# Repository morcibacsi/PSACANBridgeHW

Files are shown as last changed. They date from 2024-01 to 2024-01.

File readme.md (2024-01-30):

# PSA CAN protocol bridge (hardware)

### What is it ?
This is the hardware needed for my [PSA CAN protocol bridge][psacanbridge] software.

### v1.4

It was designed using KiCad 7.0.6 as a standalone board with an ESP32-C3 SuperMini soldered in place. It uses the MCP2515 to connect to the CAN bus of the car and the internal CAN peripheral of the ESP32 for connecting to the retrofitted peripherals. The CAN transceiver used on this board is the TJA1050 (the schematics contains a TJA1042 but they are interchangeable).

### Schema

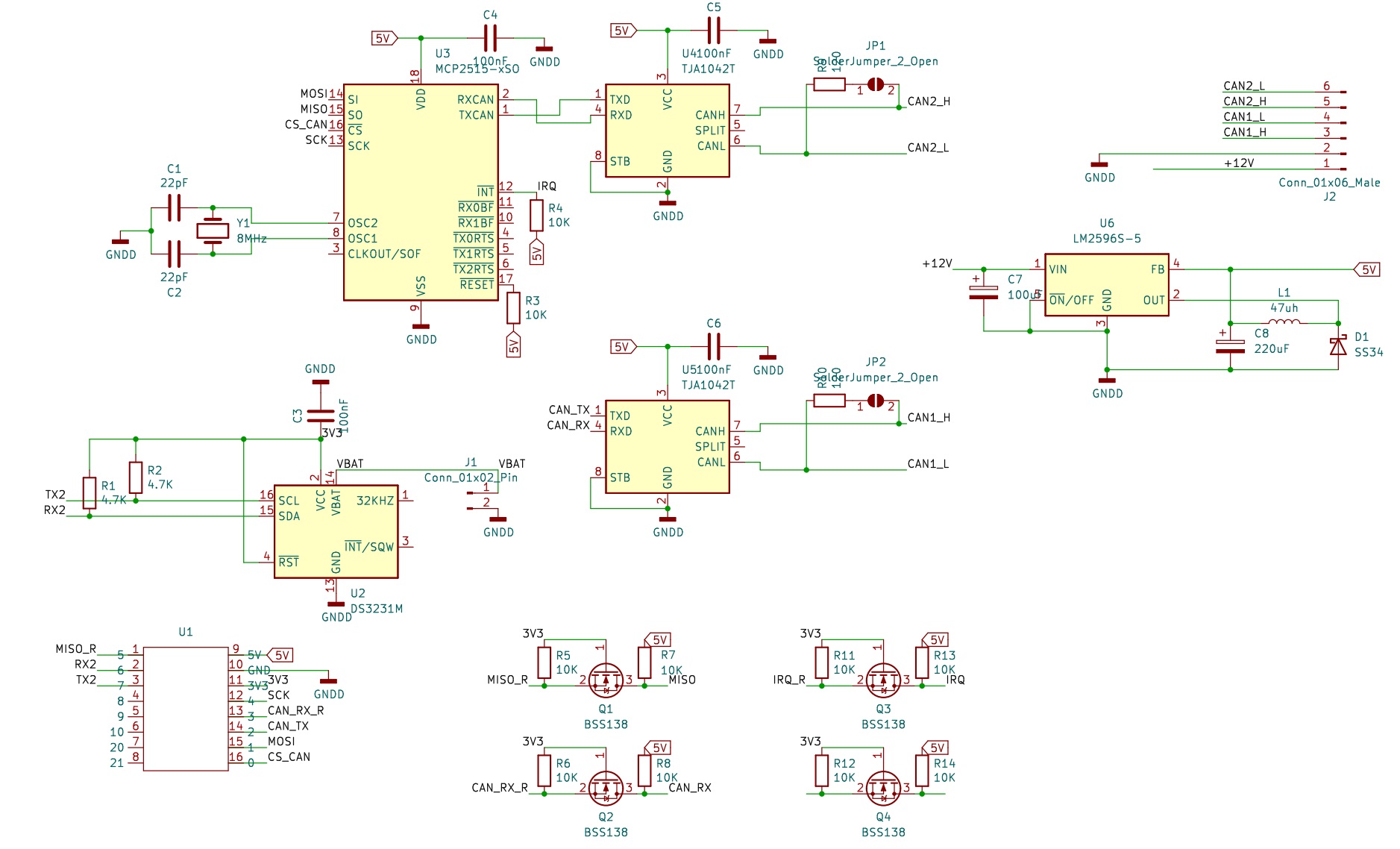
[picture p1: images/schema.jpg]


### PCB

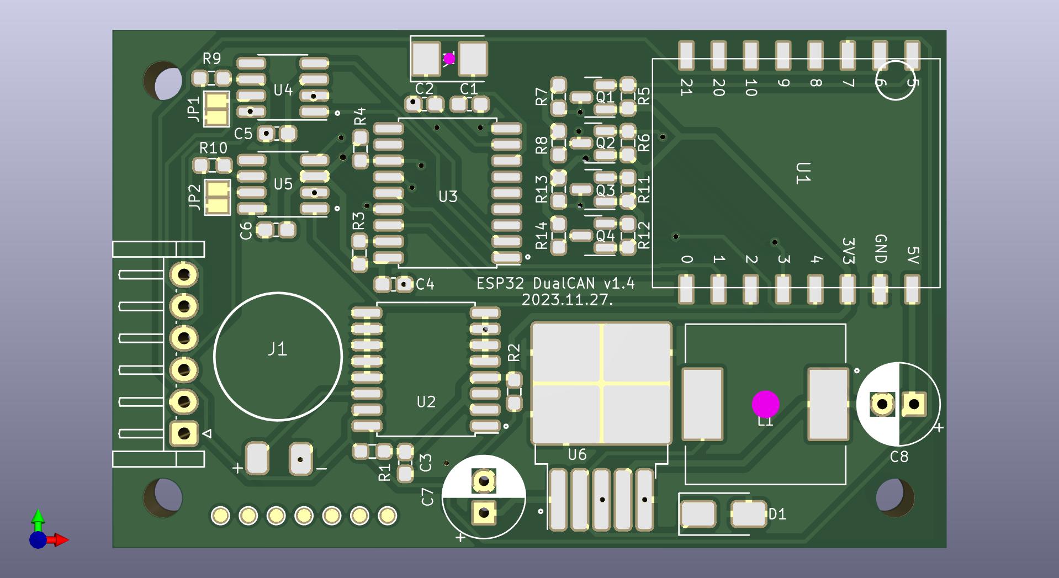
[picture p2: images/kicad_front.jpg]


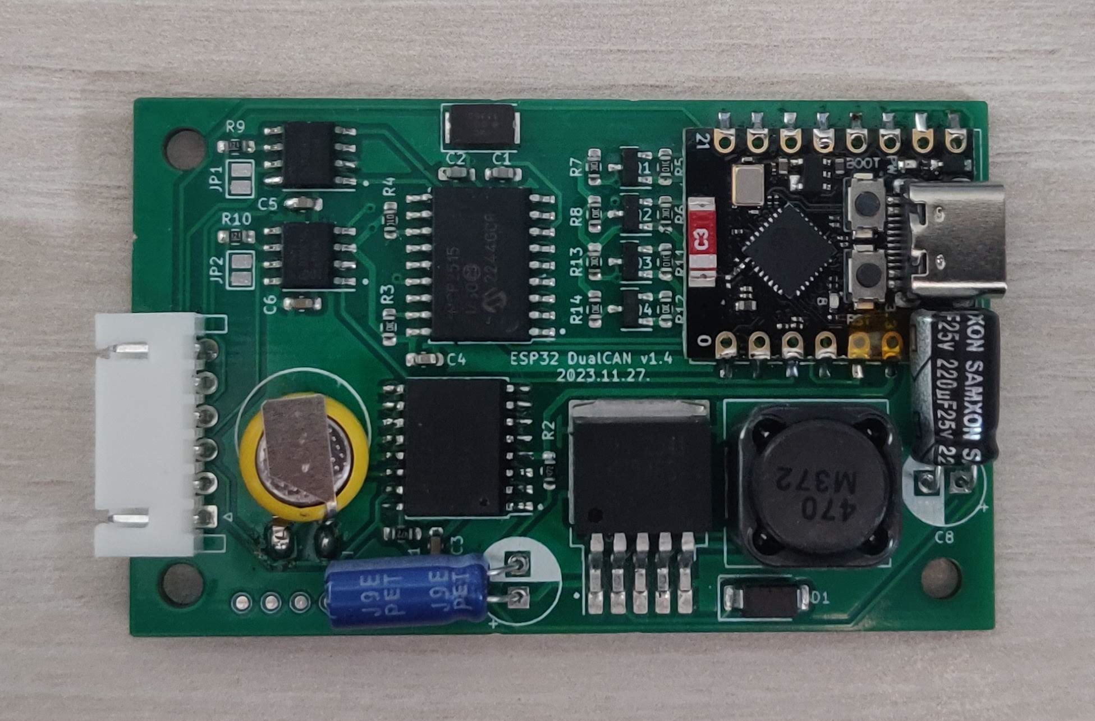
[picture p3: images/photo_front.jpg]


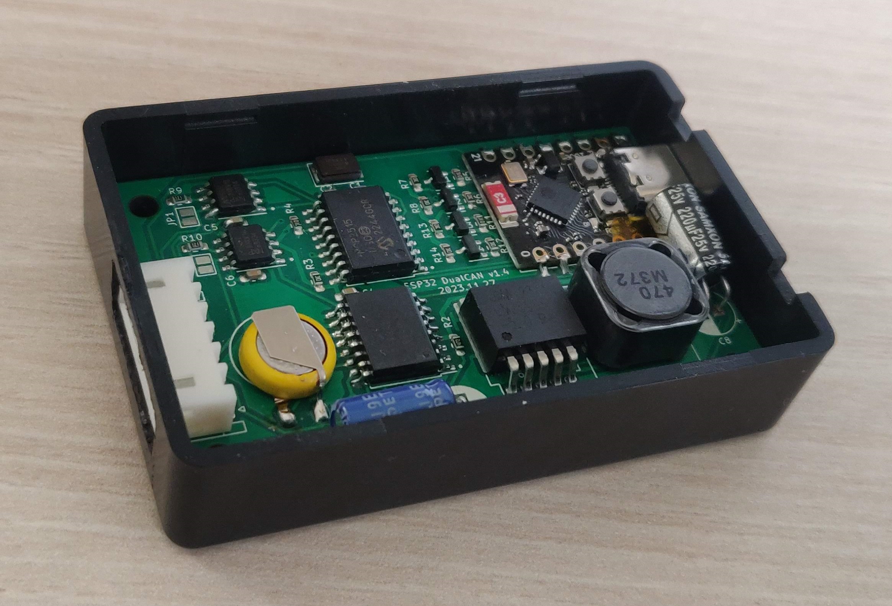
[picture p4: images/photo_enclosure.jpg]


### Assembly

The board was designed to be as compact as possible, so I suggest to send the manufacturing files to JLCPCB and order with assembly service. But in order to have a working board some soldering is also needed. You can find the necessary components in the next section.

💡 **By soldering JP1 and JP2 solder jumpers you can enable the CAN termination resistors (not needed in PSA cars)**

ESP32-C3 SuperMini

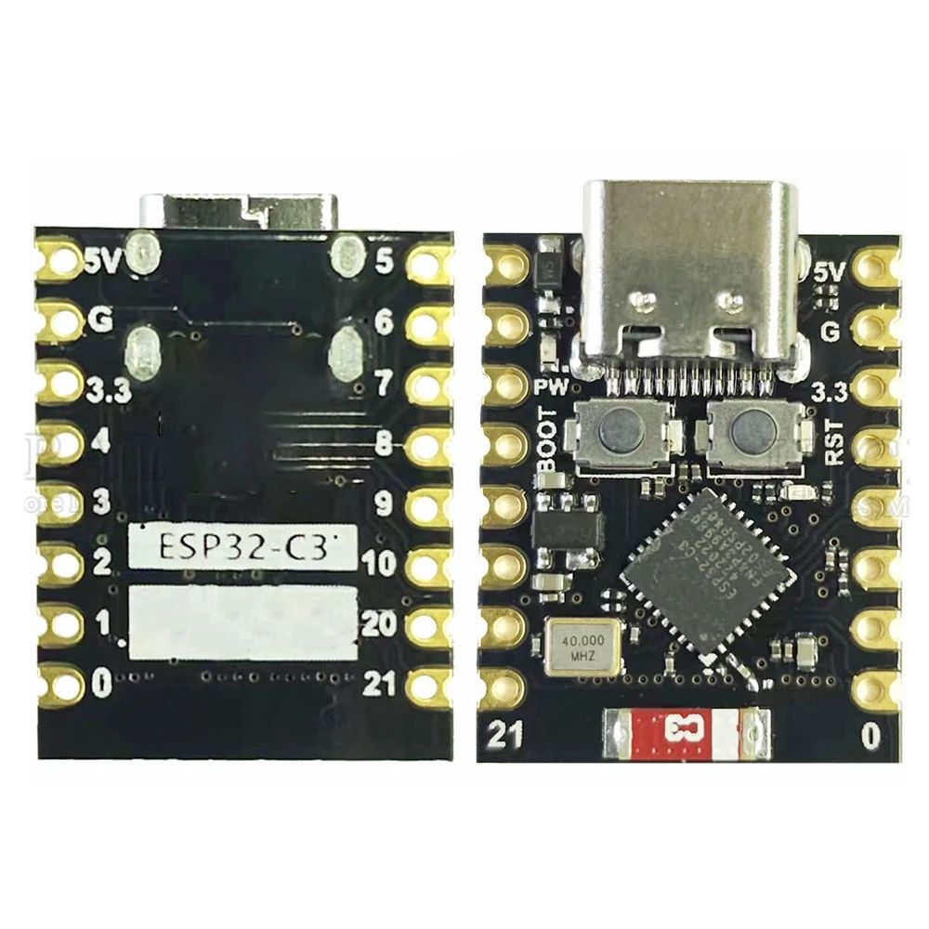
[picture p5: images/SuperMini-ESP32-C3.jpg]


I bought a [DS3231 real time clock module for Raspberry Pi][DS3231] and disassembled that and placed its parts to J1 and U2.

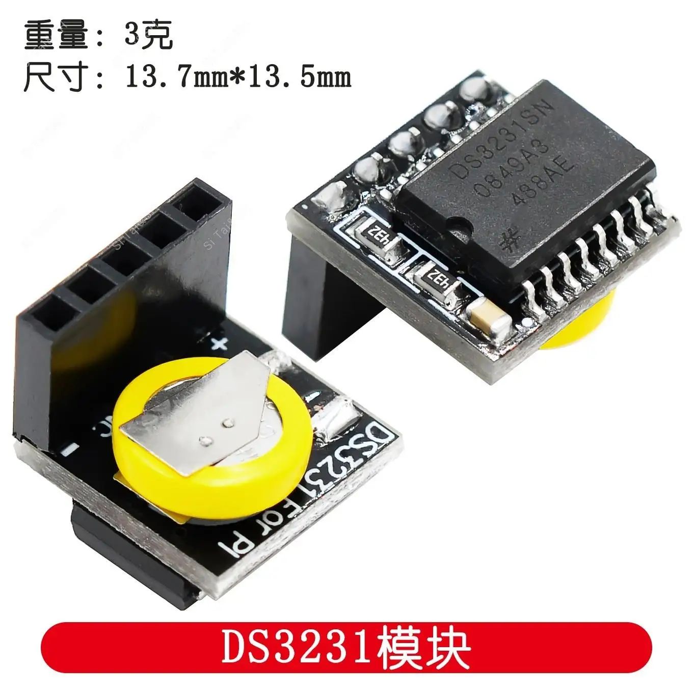
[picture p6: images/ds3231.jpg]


The board dimensions were designed to fit a [70 x 45 x 18mm case][enclosure].

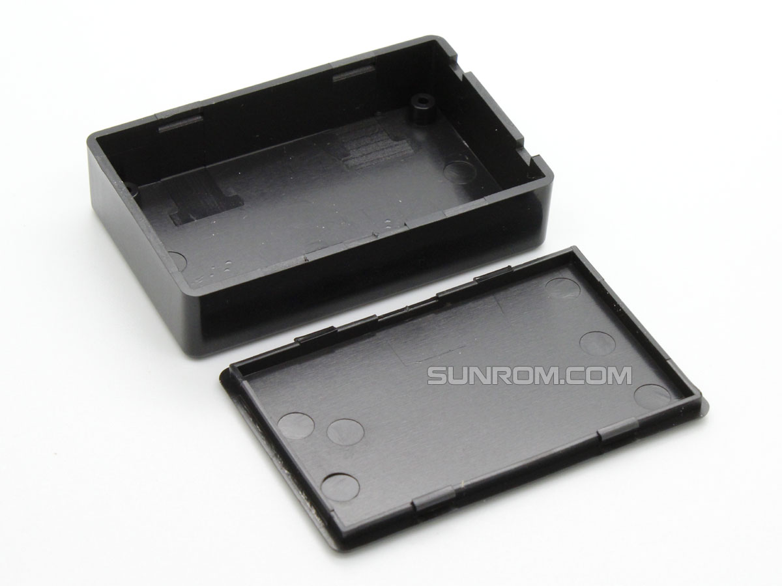
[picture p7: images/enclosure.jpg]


### BOM

I listed only those which aren't populated by the assembly company.

|Designator|Value |Package |
|---|---|---|
|J1 |Coin battery for DS3231 | |
|U2 |DS3231 |SOIC-16W_7.5x10.3mm_P1.27mm |
|C7 |100uF |Capacitor_THT:CP_Radial_D6.3mm_P2.50mm |
|C8 |220uF |Capacitor_THT:CP_Radial_D6.3mm_P2.50mm |

The connector for the power and signal wires is a JST-XH6 2.54 mm

The full BOM is in the production folder as a csv.

[psacanbridge]: https://github.com/morcibacsi/PSACANBridge
[DS3231]: https://www.aliexpress.com/item/1005006116699524.html
[enclosure]: https://www.aliexpress.com/item/1005005467281776.html

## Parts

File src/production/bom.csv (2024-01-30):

Designator | Footprint | Quantity | Value | LCSC Part #
C1, C2 | 0603 | 2 | 22pF | C1653
C3, C4, C5, C6 | 0603 | 4 | 100nF | C14663
C7 | CP_Radial_D6.3mm_P2.50mm | 1 | 100uF
C8 | CP_Radial_D6.3mm_P2.50mm | 1 | 220uF
D1 | D_SMA | 1 | SS34 | C7420365
J1 | DS3231_BatteryHolder | 1 | Conn_01x02_Pin
J2 | JST_EH_S6B-EH_1x06_P2.50mm_Horizontal | 1 | Conn_01x06_Male
JP1, JP2 | SolderJumper-2_P1.3mm_Open_Pad1.0x1.5mm | 2 | SolderJumper_2_Open
L1 | L_12x12mm_H8mm | 1 | 47uh | C167265
Q1, Q2, Q3, Q4 | SOT-23 | 4 | BSS138 | C112239
R1, R2 | 0603 | 2 | 4.7K | C25999
R10, R9 | 0603 | 2 | 120
R11, R12, R13, R14, R3, R4, R5, R6, R7, R8 | 0603 | 10 | 10K | C25804
U1 | ESP32_c3_supermini | 1 | ~
U2 | SOIC-16W_7.5x10.3mm_P1.27mm | 1 | DS3231M
U3 | SOIC-18W_7.5x11.6mm_P1.27mm | 1 | MCP2515-xSO | C12368
U4, U5 | SOIC-8_3.9x4.9mm_P1.27mm | 2 | TJA1042T | C6952
U6 | TO-263-5_TabPin3 | 1 | LM2596S-5 | C347421
Y1 | Crystal_SMD_5032-2Pin_5.0x3.2mm | 1 | 8MHz | C115962

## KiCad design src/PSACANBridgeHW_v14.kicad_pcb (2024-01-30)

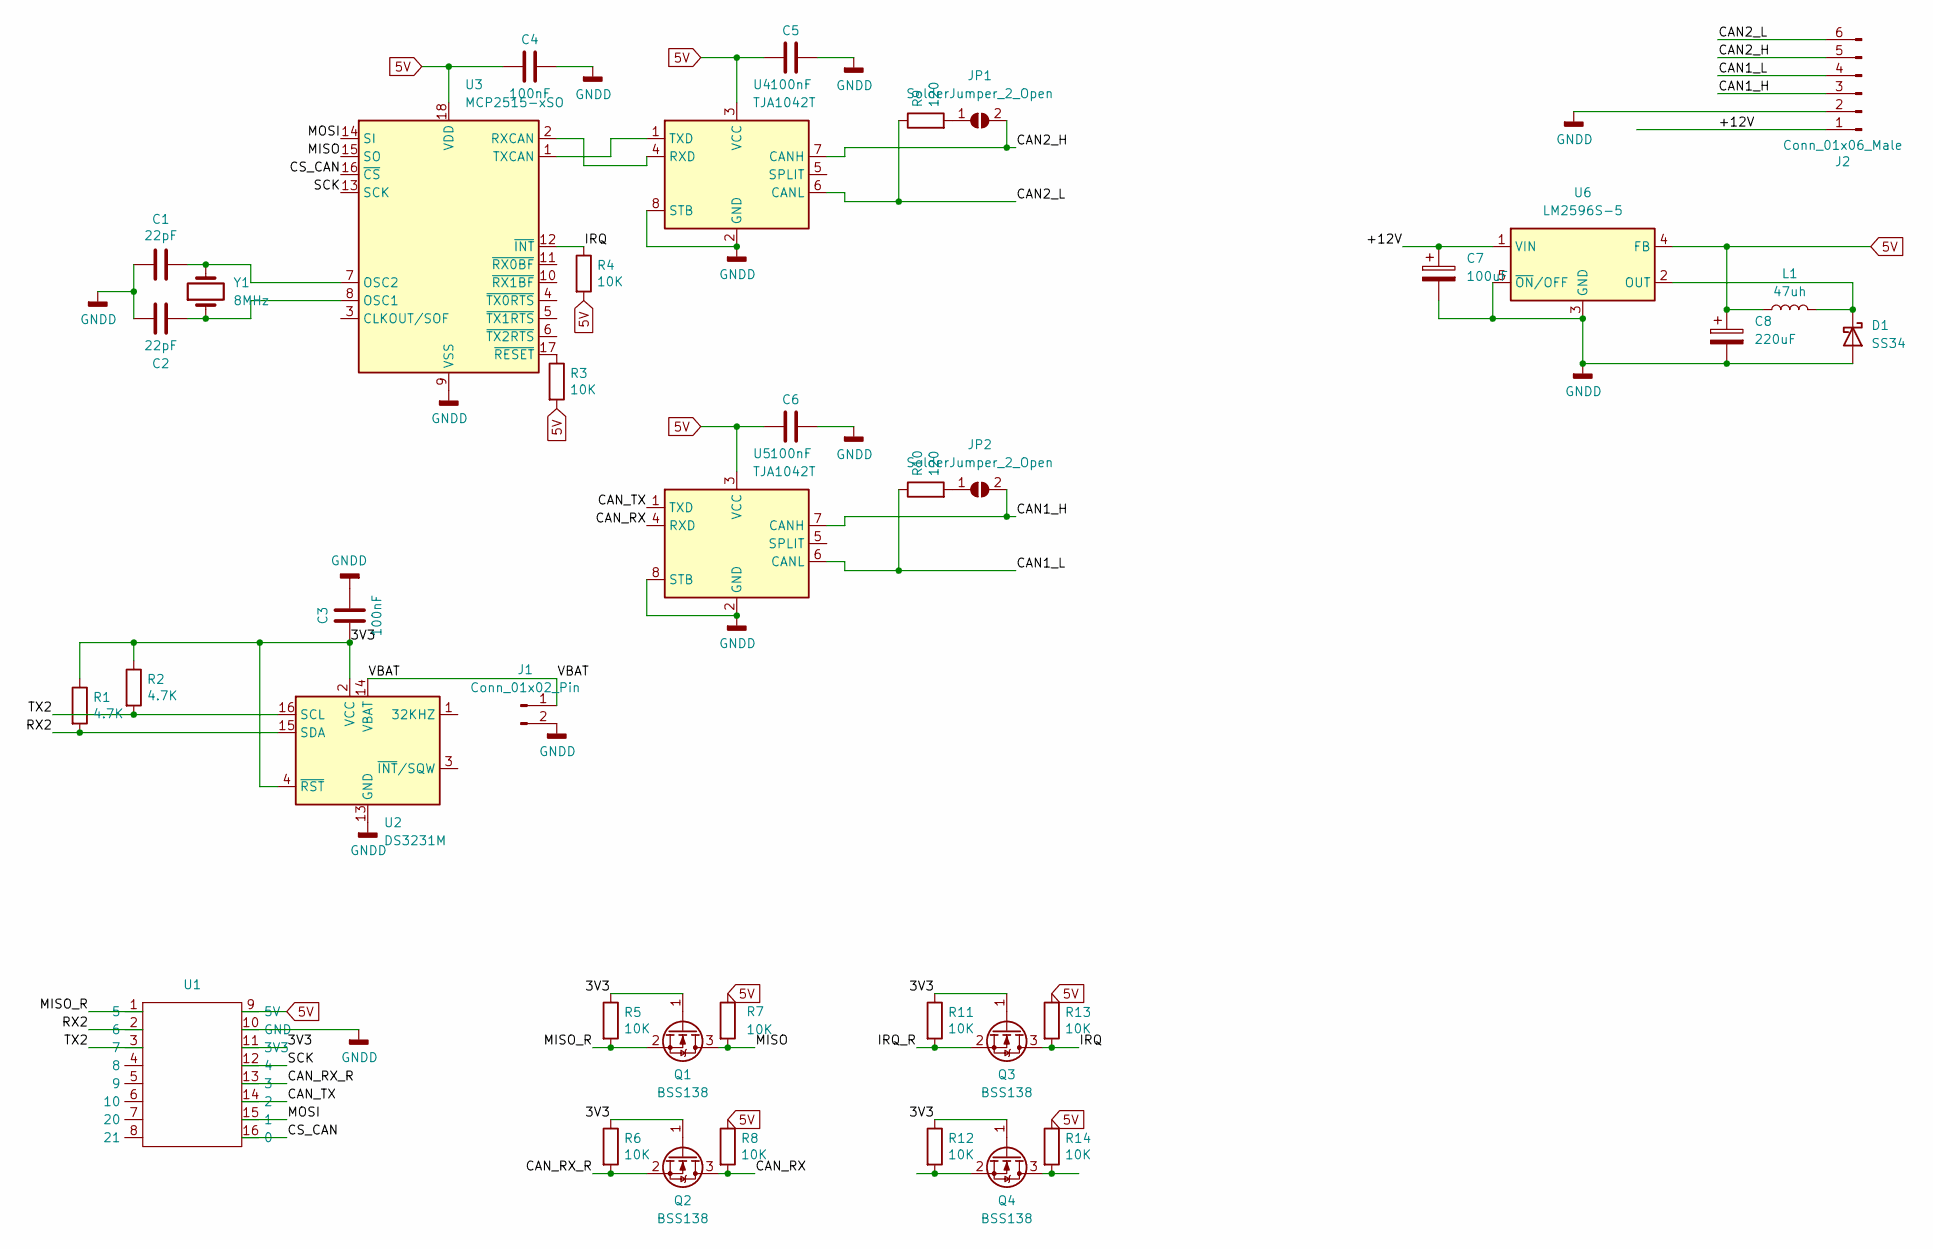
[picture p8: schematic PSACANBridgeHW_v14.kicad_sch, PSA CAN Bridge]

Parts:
C1, C2: 22pF; C_0603_1608Metric_Pad1.08x0.95mm_HandSolder; LCSC C1653
C3, C4, C5, C6: 100nF; C_0603_1608Metric_Pad1.08x0.95mm_HandSolder; LCSC C14663
C7: 100uF; CP_Radial_D6.3mm_P2.50mm
C8: 220uF; CP_Radial_D6.3mm_P2.50mm
D1: SS34; D_SMA; LCSC C7420365
J1: Conn_01x02_Pin; DS3231_BatteryHolder
J2: Conn_01x06_Male; JST_EH_S6B-EH_1x06_P2.50mm_Horizontal
JP1, JP2: SolderJumper_2_Open; SolderJumper-2_P1.3mm_Open_Pad1.0x1.5mm
L1: 47uh; L_12x12mm_H8mm; LCSC C167265
Q1, Q2, Q3, Q4: BSS138; SOT-23; LCSC C112239
R1, R2: 4.7K; R_0603_1608Metric_Pad0.98x0.95mm_HandSolder; LCSC C25999
R3, R4, R5, R6, R7, R8, R11, R12, R13, R14: 10K; R_0603_1608Metric_Pad0.98x0.95mm_HandSolder; LCSC C25804
R9, R10: 120; R_0603_1608Metric_Pad0.98x0.95mm_HandSolder
U1: ESP32_c3_supermini
U2: DS3231M; SOIC-16W_7.5x10.3mm_P1.27mm; JLCPCB Rotation Offset -90
U3: MCP2515-xSO; SOIC-18W_7.5x11.6mm_P1.27mm; LCSC C12368
U4, U5: TJA1042T; SOIC-8_3.9x4.9mm_P1.27mm; LCSC C6952
U6: LM2596S-5; TO-263-5_TabPin3; LCSC C347421
Y1: 8MHz; Crystal_SMD_5032-2Pin_5.0x3.2mm; LCSC C115962

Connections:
5V: C4.2, C5.2, C6.2, C8.1, L1.1, R3.2, R4.2, R7.1, R8.1, R13.1, R14.1, U1.9 (5V), U3.18 (VDD), U4.3 (VCC), U5.3 (VCC), U6.4 (FB)
/3V3: C3.2, Q1.1 (G), Q2.1 (G), Q3.1 (G), Q4.1 (G), R1.1, R2.1, R5.1, R6.1, R11.1, R12.1, U1.11 (3V3), U2.2 (VCC), U2.4 (~RST)
/+12V: C7.1, J2.1, U6.1 (VIN)
/CAN1_H: J2.3, JP2.2 (B), U5.7 (CANH)
/CAN1_L: J2.4, R10.1, U5.6 (CANL)
/CAN2_H: J2.5, JP1.2 (B), U4.7 (CANH)
/CAN2_L: J2.6, R9.1, U4.6 (CANL)
/CAN_RX: Q2.3 (D), R8.2, U5.4 (RXD)
/CAN_RX_R: Q2.2 (S), R6.2, U1.13 (3)
/CAN_TX: U1.14 (2), U5.1 (TXD)
/CS_CAN: U1.16 (0), U3.16 (~CS)
/IRQ: Q3.3 (D), R4.1, R13.2, U3.12 (~INT)
/IRQ_R: Q3.2 (S), R11.2
/MISO: Q1.3 (D), R7.2, U3.15 (SO)
/MISO_R: Q1.2 (S), R5.2, U1.1 (5)
/MOSI: U1.15 (1), U3.14 (SI)
/RX2: R1.2, U1.2 (6), U2.15 (SDA)
/SCK: U1.12 (4), U3.13 (SCK)
/TX2: R2.2, U1.3 (7), U2.16 (SCL)
/VBAT: J1.1, U2.14 (VBAT)
GNDD: C1.2, C2.2, C3.1, C4.1, C5.1, C6.1, C7.2, C8.2, D1.2 (A), J1.2, J2.2, U1.10 (GND), U2.5 (GND), U2.6 (GND), U2.7 (GND), U2.8 (GND), U2.9 (GND), U2.10 (GND), U2.11 (GND), U2.12 (GND), U2.13 (GND), U3.9 (VSS), U4.2 (GND), U4.8 (STB), U5.2 (GND), U5.8 (STB), U6.3 (GND), U6.5 (~ON/OFF)
unnamed: D1.1 (K), L1.2, U6.2 (OUT)
unnamed: JP1.1 (A), R9.2
unnamed: JP2.1 (A), R10.2
unnamed: Q4.3 (D), R14.2
unnamed: Q4.2 (S), R12.2
unnamed: C2.1, U3.8 (OSC1), Y1.1
unnamed: C1.1, U3.7 (OSC2), Y1.2
unnamed: U3.2 (RXCAN), U4.4 (RXD)
unnamed: U3.1 (TXCAN), U4.1 (TXD)
unnamed: R3.1, U3.17 (~RESET)

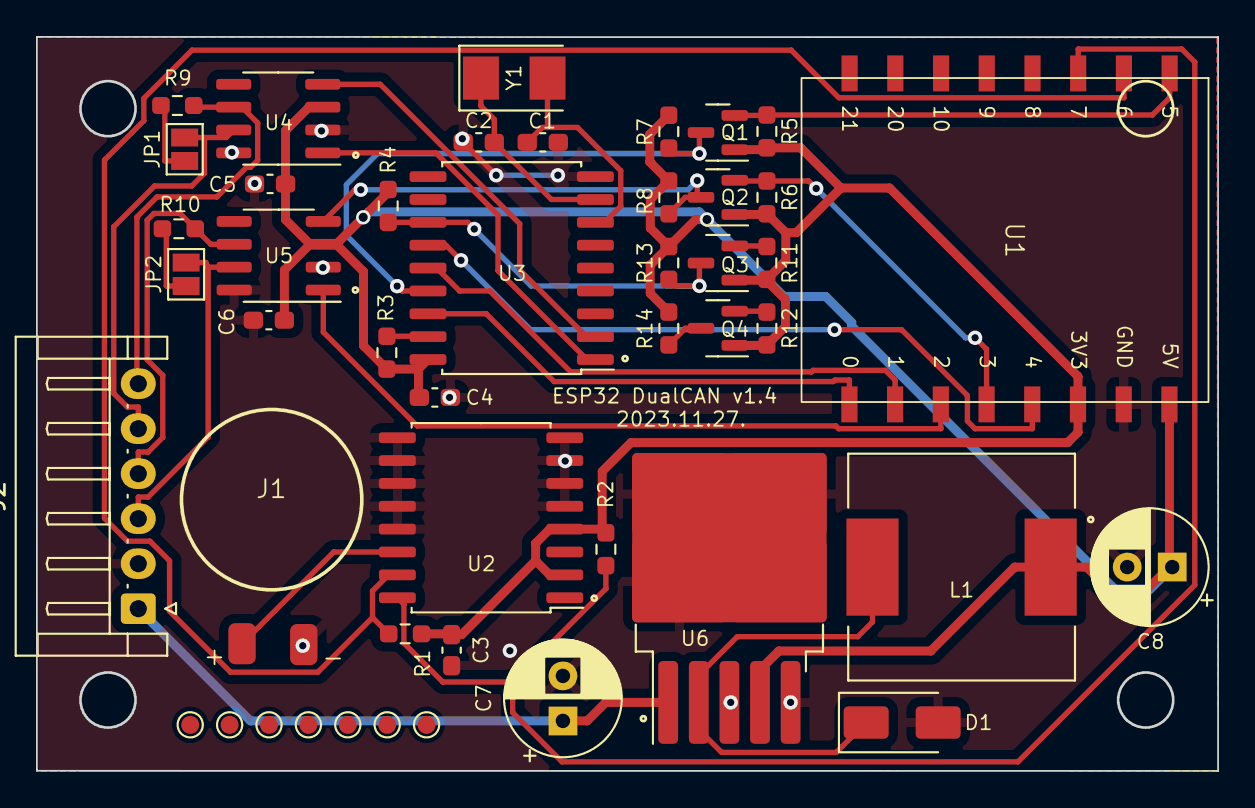
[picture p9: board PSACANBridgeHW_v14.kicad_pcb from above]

Board: 2 copper layers, 65.6 x 40.8 mm, 39 parts (0 on the bottom side), 31 nets.
